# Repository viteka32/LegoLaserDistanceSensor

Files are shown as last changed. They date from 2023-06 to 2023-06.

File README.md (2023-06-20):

# LEGO® laser distance sensor
LEGO® laser distance sensor is open-source, which is used for robust distance measuring in educational robotic applications with LEGO® Mindstorms kits.
Advantages over the original LEGO® ultrasonic sensor:

 - Extended measurement range of up to 400 cm
 - Lower susceptibility to interference from other sensors
 - The refresh rate of up to 50 Hz
 - Based on [VL53L1x](https://www.st.com/en/imaging-and-photonics-solutions/vl53l1x.html) and [RP2040](https://www.raspberrypi.com/products/rp2040/)

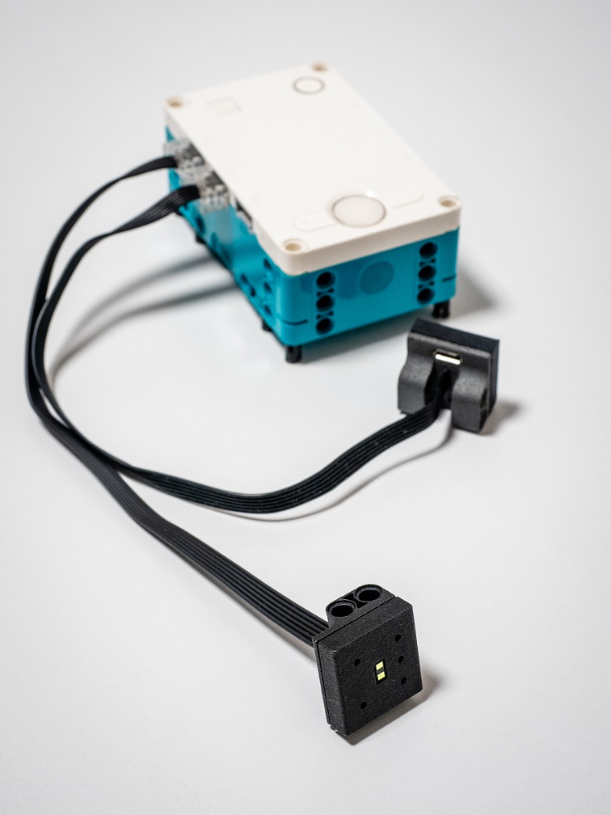
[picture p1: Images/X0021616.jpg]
Sensor


## LEGO® Mindstorms
The laser sensor is recognized in the LEGO® Mindstorms app as an original ultrasonic sensor. You can therefore use standard blocks for distance measurement.

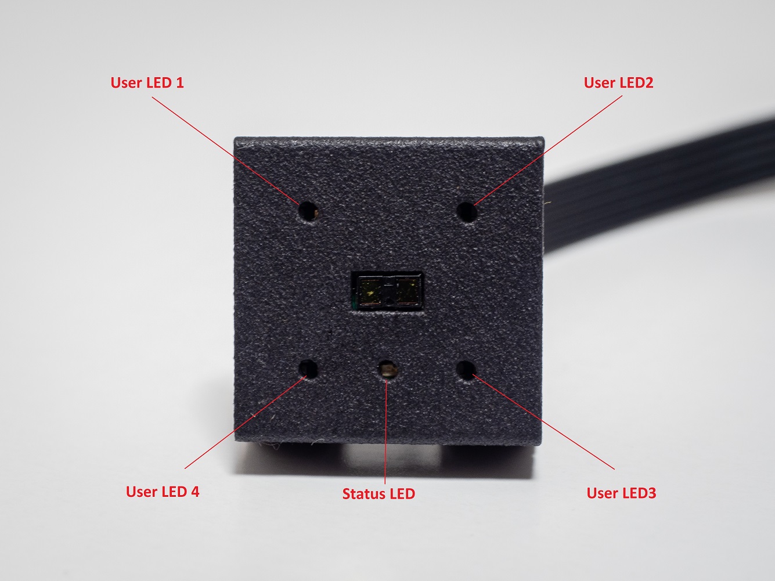
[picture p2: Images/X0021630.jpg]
LED description


#### Connection signalization
When connecting the laser sensor to LEGO® Spike/EV3, the status LED will flash. Once the laser sensor and LEGO® Spike/EV3 are correctly connected, the status LED will remain on.

#### Known issues
The laser sensor does not currently support additional LED illumination, making it incompatible with the ultrasonic sensor as a direct replacement.

## Hardware
The hardware is designed to operate with a power supply of either 3.3V or 5V, utilizing a low-drop LDO. The sensor can be used with LEGO® Spike (3.3V) or LEGO® EV3 (5V). For use with LEGO® EV3, an adapter is required to connect the sensor to the EV3 RJ12 connector. Alternatively, the laser distance sensor can be connected via a micro USB connector for programming custom applications in MicroPython or for use with a custom robotic application, such as Raspberry Pi.

### Issues - not tested
<span style="color:red">
The power supply control logic, which switches between the micro USB connector and the LEGO® Powered Up connector, has not been tested yet. We recommend unsoldering diode D6 and soldering resistor R15 (0R) to use the power supply solely from the LEGO® Powered Up connector.
</span>

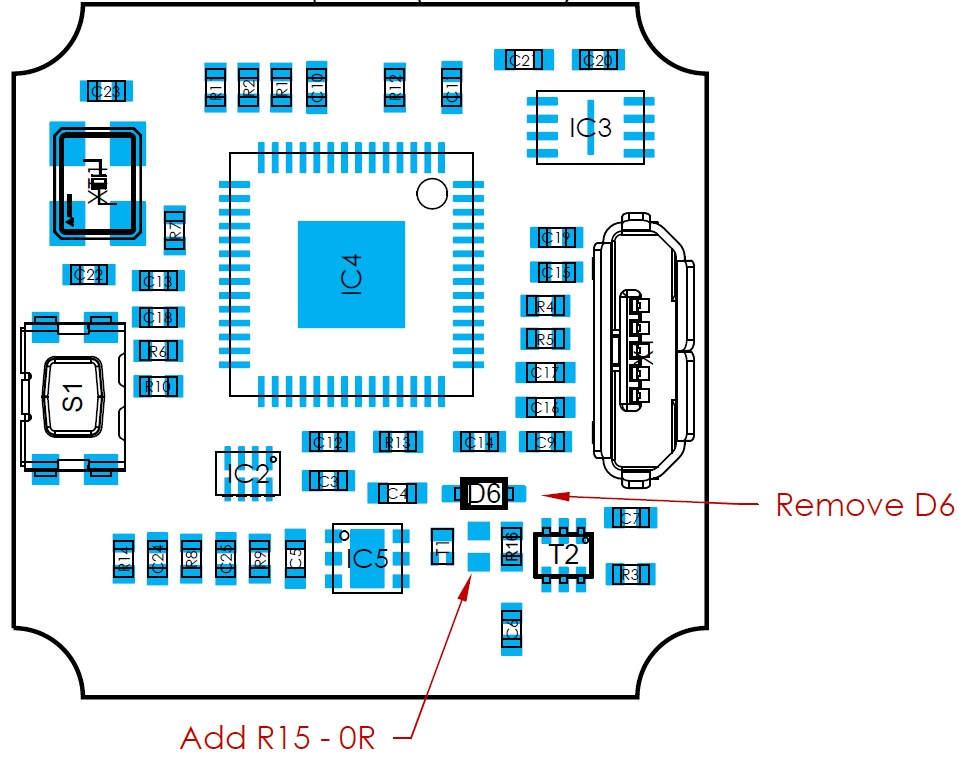
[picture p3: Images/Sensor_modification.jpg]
Sensor modification


### LEGO® Powered Up connector
https://www.aliexpress.com/item/1005004076370021.html?spm=a2g0o.order_list.order_list_main.98.2dce1802ppkqRz

## CAD models
The CAD folder contains files of the sensor case. It was designed for MJF 3D printer and it is recommended to use this type of printer.

## Software
### Requirements

- Python 3
- pip3
- rshell

#### Installing rshell
Linux:

```
pip3 install rshell
```

Windows:

```
python.exe -m pip install --upgrade pip
```

## How to bring the sensor up

### Flashing MicroPython Firmware
1. Press and hold the BOOTSEL button and plug your Lego Distance Sensor into the USB port of your computer. Release the BOOTSEL button after your Lego Distance Sensor is connected.
2. It will be detected as a Mass Storage Device called RPI-RP2.
3. Drag and drop the MicroPython UF2 file onto the RPI-RP2 storage.
4. Your Lego Distance Sensor will reboot and should be rediscovered by your system. If yes, you are now running MicroPython otherwise repeat step 1.
5. You can access micropython console using the REPL via USB Serial.

### Uploading Sensor Application Files
1. Connect to the Lego Distance Sensor's serial port from the command line.

   Linux:

   ```
   rshell -p /dev/ttyXXX --buffer-size 512
   ```

   Windows:

   ```
   rshell -p comXXX --buffer-size 512
   ```

2. Upload \*.py files

    ```
    cp main.py VL53L1X.py /pyboard
    ```

3. Verify that the \*.py files were successfully written.

    ```
    ls /pyboard
    ```

Alternatively, you can run a single command to perform these steps:

- Linux:

  ```
  rshell -p /dev/ttyXXX --buffer-size 512 cp main.py VL53L1X.py LPF2.py /pyboard
  ```

- Windows:

  ```
  rshell -p comXXX --buffer-size 512 cp main.py VL53L1X.py LPF2.py /pyboard
  ```

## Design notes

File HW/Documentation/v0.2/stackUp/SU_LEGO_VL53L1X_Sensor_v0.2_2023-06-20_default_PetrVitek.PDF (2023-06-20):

# Board Stack Report

Stack Up | Layer Stack
Layer | Board Layer Stack | Name | Material | Thickness | Constant

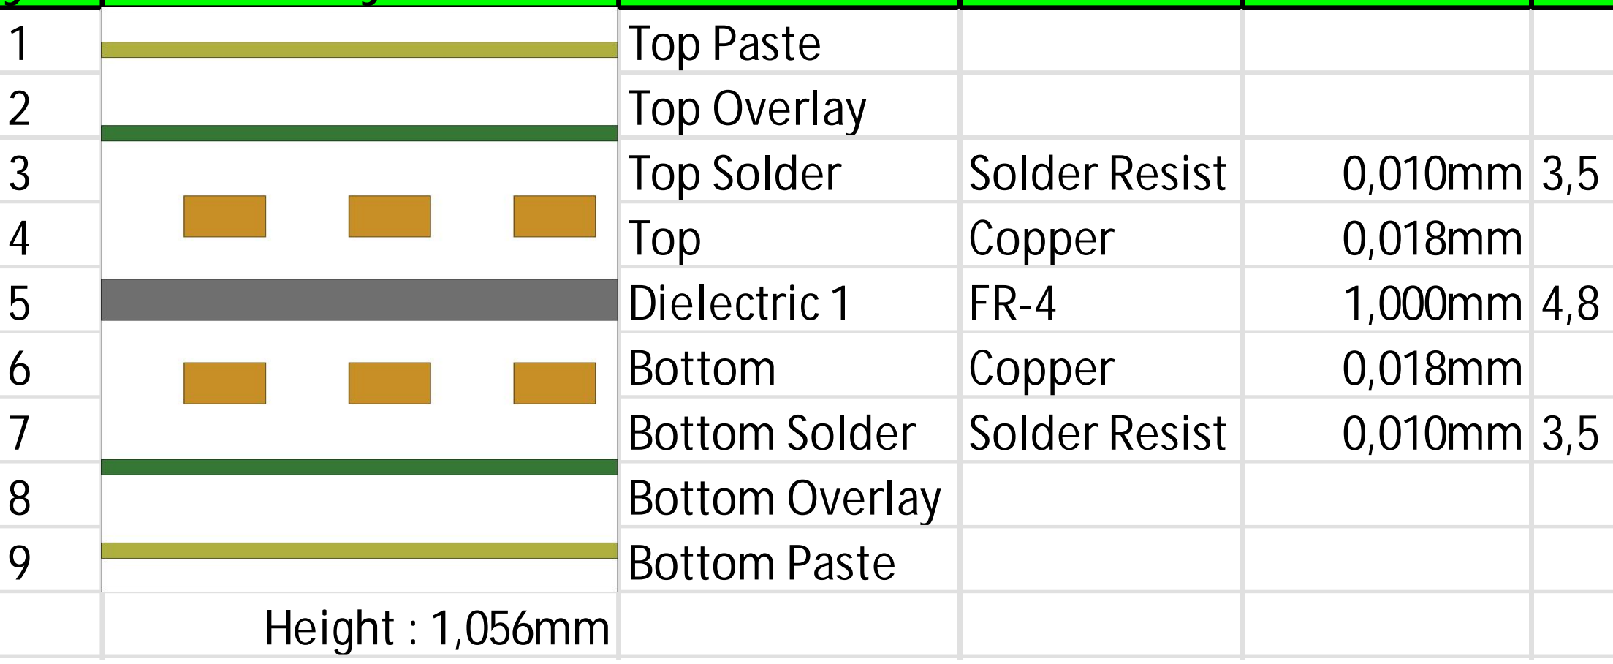
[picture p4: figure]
Top Paste; Top Overlay; Top Solder; Solder Resist; Top; Copper; Dielectric 1; Bottom; Bottom Solder; Bottom Overlay; Bottom Paste; Height : 1,056mm

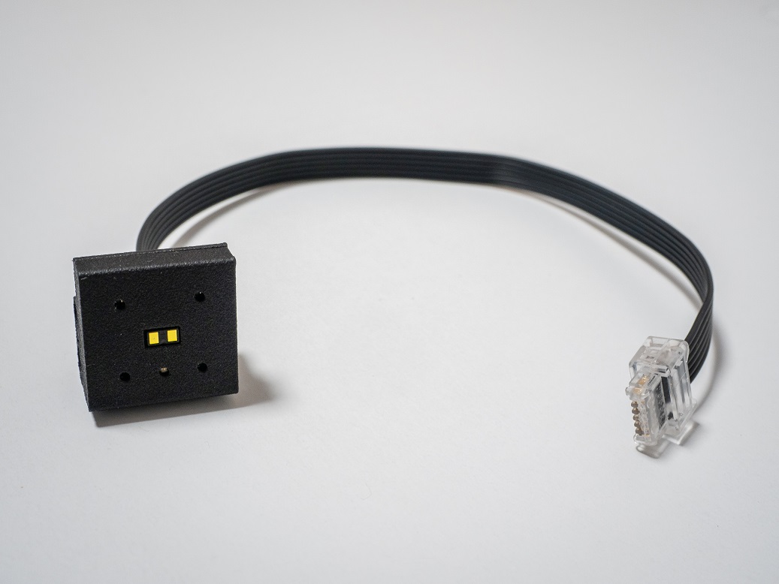
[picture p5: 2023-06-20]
Images/X0021620.jpg

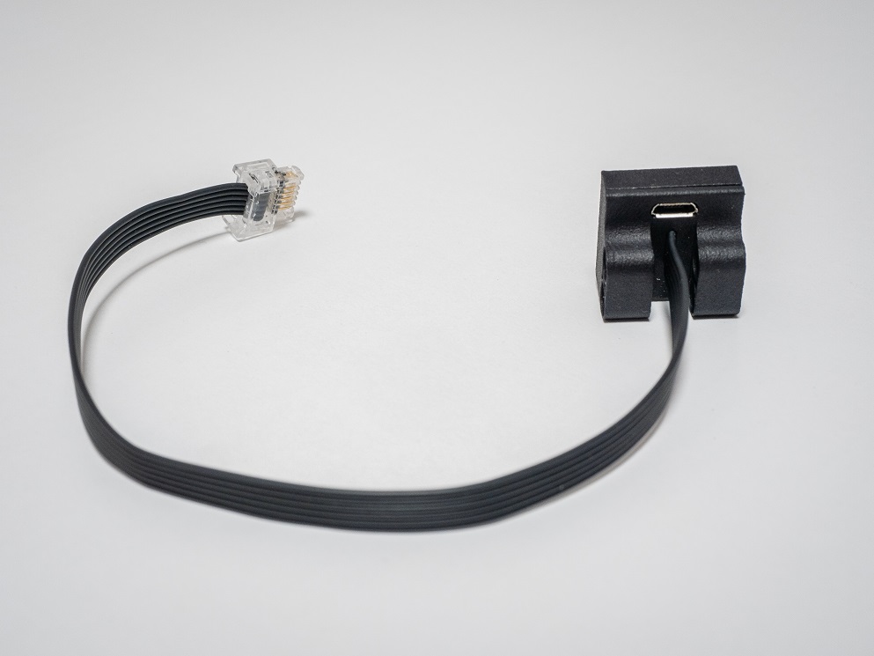
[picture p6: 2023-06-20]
Images/X0021623.jpg

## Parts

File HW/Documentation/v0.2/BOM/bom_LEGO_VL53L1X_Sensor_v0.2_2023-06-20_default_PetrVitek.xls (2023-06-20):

 |  |  |  |  |  |  |  |  |  |  | Release Date
 | Bill of Materials for | Lego Spike/EV3 Laser |  |  |  |  |  |  |  |  | 20.06.2023
 | Assembly Variant | default |  | Project Revision | v0.2
# | Reference | Value | Quantity | Package | Manufacturer | Part Number | Description | Supplier | Supplier Part Number | SZ | RČ
1 | C1, C3, C6, C7, C9, C10, C11, C12, C13, C14, C15, C18, C19, C20 | 100nF 25V | 14 | C0402 | Walsin Technologies | 0402B104K250CT | WALSIN - 0402B104K250CT - CAPACITOR, MLCC, X7R, 0.1UF, 25V, 0402 | Farnell | 2496772
2 | C2, C4, C5, C16, C17, C21 | 4.7uF/10V | 6 | C0402_big | Murata | GRM155R61A475MEAAD | MURATA - GRM155R61A475MEAAD - CAP, MLCC, X5R, 4.7UF, 10V, 0402 | Farnell | 2688503
3 | C22, C23 | 27pF 50V | 2 | C0402 | Walsin Technologies | 0402N270J500CT | WALSIN - 0402N270J500CT - CAPACITOR, MLCC, NP0, 27PF, 50V, 0402 | Farnell | 2496801
4 | C24, C25 | 10pF / 50V | 2 | C0402 | KEMET | C0402C100D5GAC | Kategorie produktu: Vícevrstvé keramické kondenzátory MLCC – pro povrchovou montáž SMD, SMT Výrobce: KEMET RoHS:: V souladu RoHS Údaje Série: C-C Kapacita: 10 pF Jmenovité napětí (DC) stejnosměrného proudu : 50 VDC Dielektrikum: C0G (NP0) Tolerance: 0.5 pF Kód pouzdra - palce: 0402 Kód pouzdra - mm: 1005 Výška: - Maximální provozní teplota: + 125 C Minimální provozní teplota: - 55 C Koncovka: - Výrobek: General Type MLCCs Obal: Cut Tape Obal: MouseReel Obal: Ree | Mouser | 80-C0402C100D5GAC
5 | D1, D2, D3, D4, D5 | KPH-1608SGC | 5 | LED0603 | Kingbright | KPH-1608SGC | KINGBRIGHT - KPH-1608SGC - LED, GREEN, 12MCD, 568NM, SMD LED 0603 zelená | Farnell | 2426215
6 | D6 | BAS716,115 | 1 | SOD523 | Nexperia | BAS716,115 | NEXPERIA - BAS716,115 - Small Signal Diode, Single, 85 V, 200 mA, 1.25 V, 3 µs, 4 A | Farnell | 8734500
7 | IC1 | VL53L1CXV0FY/1 | 1 | VL53L1X | STMicroelectronics | VL53L1CXV0FY/1 | STMICROELECTRONICS - VL53L1CXV0FY/1 - Proximity Sensor, I2C, 4000 mm, OLGA, 12 Pins, 2.6 V, 3.5 V | Farnell | 2851946
8 | IC2 | TXS0102DQMR | 1 | X2SON-8_1.8x1.2 | Texas Instruments | TXS0102DQMR | TEXAS INSTRUMENTS - TXS0102DQMR - Voltage Level Translator, 2 Inputs, 4.2ns, 1.65V to 5.5V, X2SON-8 | Farnell | 3050430
9 | IC3 | W25Q16JVUXIQ | 1 | USON-8_3x2 | Winbond | W25Q16JVUXIQ TR | Flash NOR spiFlash, 3V, 16M-bit, 4Kb Uniform Sector, DTR | Mouser | 454-W25Q16JVUXIQTR
10 | IC4 | RP2040CT | 1 | QFN56 | Raspberry Pi | RP2040CT | RASPBERRY-PI - RP2040CT - ARM MCU, RP2040 Series Microcontrollers, ARM Cortex-M0+, 32bit, 133 MHz, 16 MB, 264 KB | Farnell | 3766082
11 | IC5 | NCP705MT33TCG | 1 | WDFN6 | ON Semiconductor | NCP705MT33TCG | Regulátory napětí s nízkým úbytkem (LDO) 500 MA LDO ULTRA-LOW IQ | Mouser | 863-NCP705MT33TCG
12 | R1, R2, R3, R10, R11, R12, R13, R14 | 2k2 | 8 | R0402 | Vishay | CRCW04022K20FKED | VISHAY - CRCW04022K20FKED. - RES, THICK FILM, 2K2, 1%, 0.063W, 0402 | Farnell | 2140802
13 | R4, R5, R8, R9 | 27R | 4 | R0402 | Vishay | CRCW040227R0FKED | VISHAY - CRCW040227R0FKED. - SMD Chip Resistor, 27 ohm, ± 1%, 62.5 mW, 0402 [1005 Metric], Thick Film, General Purpose | Farnell | 2140614
14 | R6, R7, R16 | 1k 1% | 3 | R0402 | Vishay Dale | CRCW04021K00FKED | VISHAY - CRCW04021K00FKED - RES, THICK FILM, 1K, 1%, 0.063W, 0402 | Farnell | 1469662
15 | S1 | KMR211G LFS | 1 | ButtonKMR2 | ITT C&K | KMR211GLFS | C & K COMPONENTS - KMR211G LFS - SWITCH, SPST, 0.05A, 32VDC, SMD | Farnell | 1437635
16 | T1 | PBSS2515M | 1 | DFN1006-3 | NXP Semiconductors | PBSS2515M,315 | NEXPERIA - PBSS2515M,315 - TRANSISTOR, BIPOLAR | Mouser | 771-PBSS2515M315
17 | T2 | EMH53T2R | 1 | SOT-563-6 | Rohm | EMH53T2R | ROHM - EMH53T2R - Bipolar Pre-Biased / Digital Transistor, Dual NPN, 50 V, 100 mA, 4.7 kohm | Farnell | 3757495
18 | X1 | USB3131-30-0230-A | 1 | USB3131-XX-0230-X | Global Connector Technology | USB3131-30-0230-A | GCT (GLOBAL CONNECTOR TECHNOLOGY) - USB3131-30-0230-A - USB Connector, Micro USB Type B, USB 2.0, Receptacle, 5 Ways, Through Hole Mount, Vertical | Farnell | 2537022
19 | XT1 | 12 MHz | 1 | ABM8 | Abracon | ABM8-12.000MHZ-B2-T | Krystaly 12.0 MHZ 18PF 20PPM 120OHM | Mouser | 815-ABM8-12-B2-T
 |  | Total Quantity | 55

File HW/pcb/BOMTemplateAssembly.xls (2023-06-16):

 |  |  |  |  |  |  |  |  |  |  | Release Date
 | Bill of Materials for | Field=projectTitle |  |  |  |  |  |  |  |  | Field=ReportDate
 | Assembly Variant | Field=VariantName |  | Project Revision | Field=projectRevision
# | Reference | Value | Quantity | Package | Manufacturer | Part Number | Description | Supplier | Supplier Part Number | SZ | RČ
1
2
3
 |  | Total Quantity | 0

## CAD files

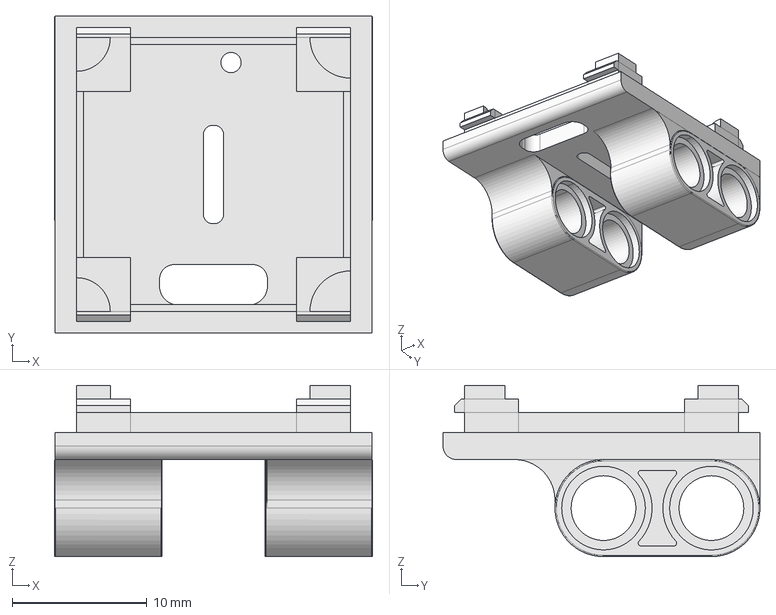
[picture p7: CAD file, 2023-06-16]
CAD/CaseBottom.step
23.6 x 23.5 x 12.7 mm

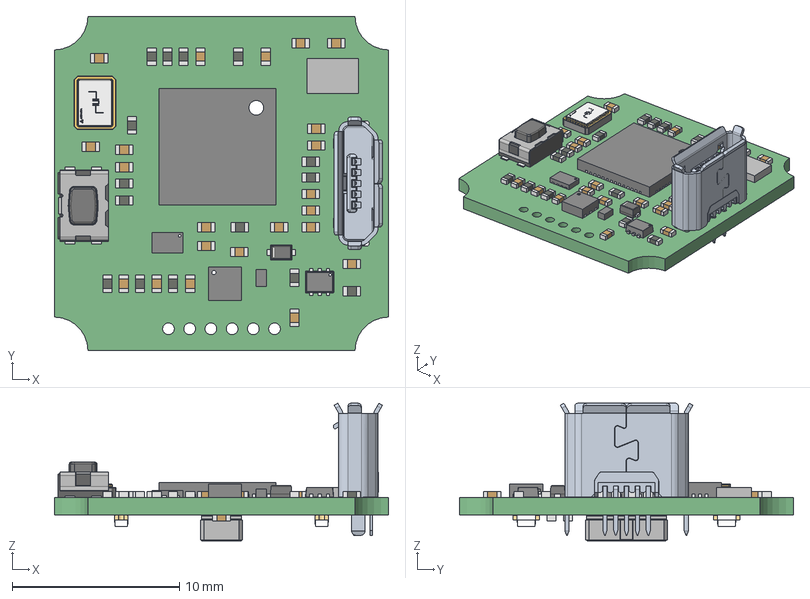
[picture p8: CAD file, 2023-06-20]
HW/Documentation/v0.2/Step/STEP_LEGO_VL53L1X_Sensor_v0.2_2023-06-20_default_PetrVitek.step
20.0 x 20.0 x 8.24 mm
Extruded x 118
bigPin
smallPine x 2
lead x 6
SOD-523F
User Library-Switch-CK-KMR2_Button
User Library-Switch-CK-KMR2_Boitier
User Library-Switch-CK-KMR2_Tole
User Library-Switch-CK-KMR2_Pads
Thermal_Shape x 2
housing x 5
cover x 5
base x 10
Polarity Mark x 5
MSBR-3
MSBR-4
MSBR-6
MSBR-5
MSBR-7
MSBR-1
MSBR-2
bracon Logo yure
pcb
kork
pads
blend
lens
main
blocker

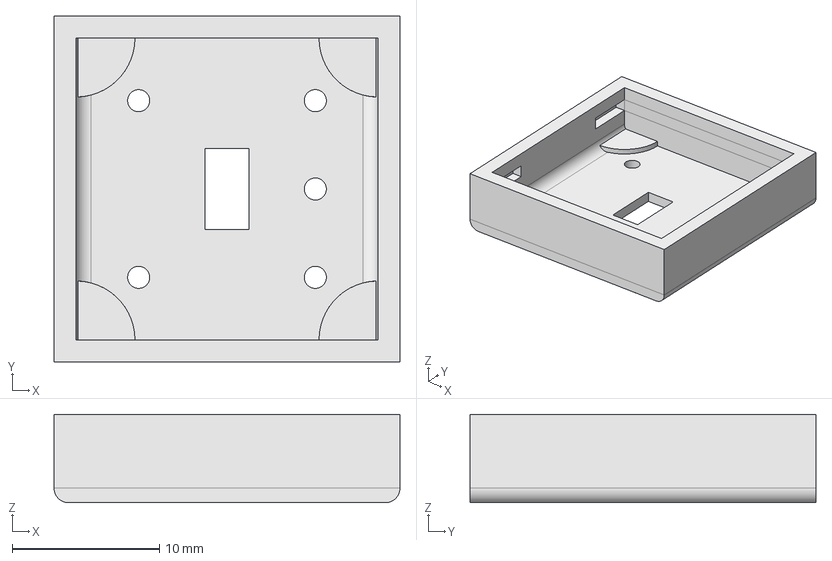
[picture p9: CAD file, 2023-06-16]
CAD/CaseTop.step
23.5 x 23.5 x 6.00 mm

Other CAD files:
HW/Documentation/v0.2/Step/STEP_LEGO_VL53L1X_Sensor_v0.2_2023-02-10_default_PetrVitek.step
CAD/CaseBottom.FCStd
CAD/CaseBottom.stl
CAD/CaseTop.FCStd
CAD/CaseTop.stl

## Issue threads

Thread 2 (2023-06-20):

Test and rework power supply control logic

viteka32, 2023-06-20:

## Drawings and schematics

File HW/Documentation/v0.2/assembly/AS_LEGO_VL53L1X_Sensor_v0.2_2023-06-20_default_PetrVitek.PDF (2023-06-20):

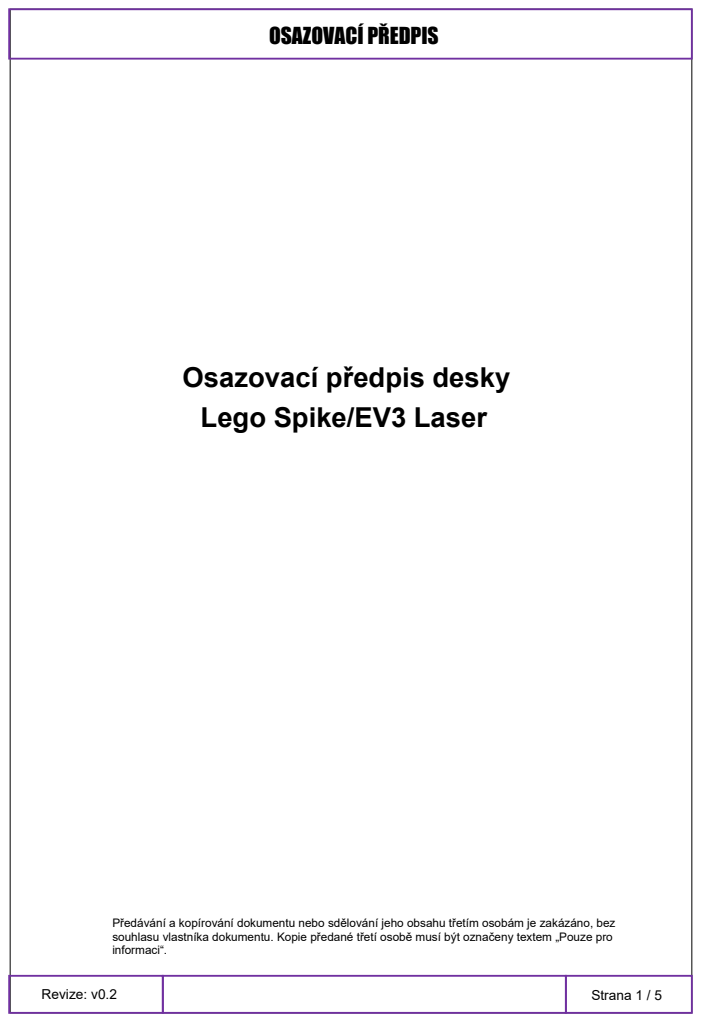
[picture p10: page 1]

Předávání a kopírování dokumentu nebo sdělování jeho obsahu třetím osobám je zakázáno, bez
souhlasu vlastníka dokumentu. Kopie předané třetí osobě musí být označeny textem „Pouze pro
informaci“.

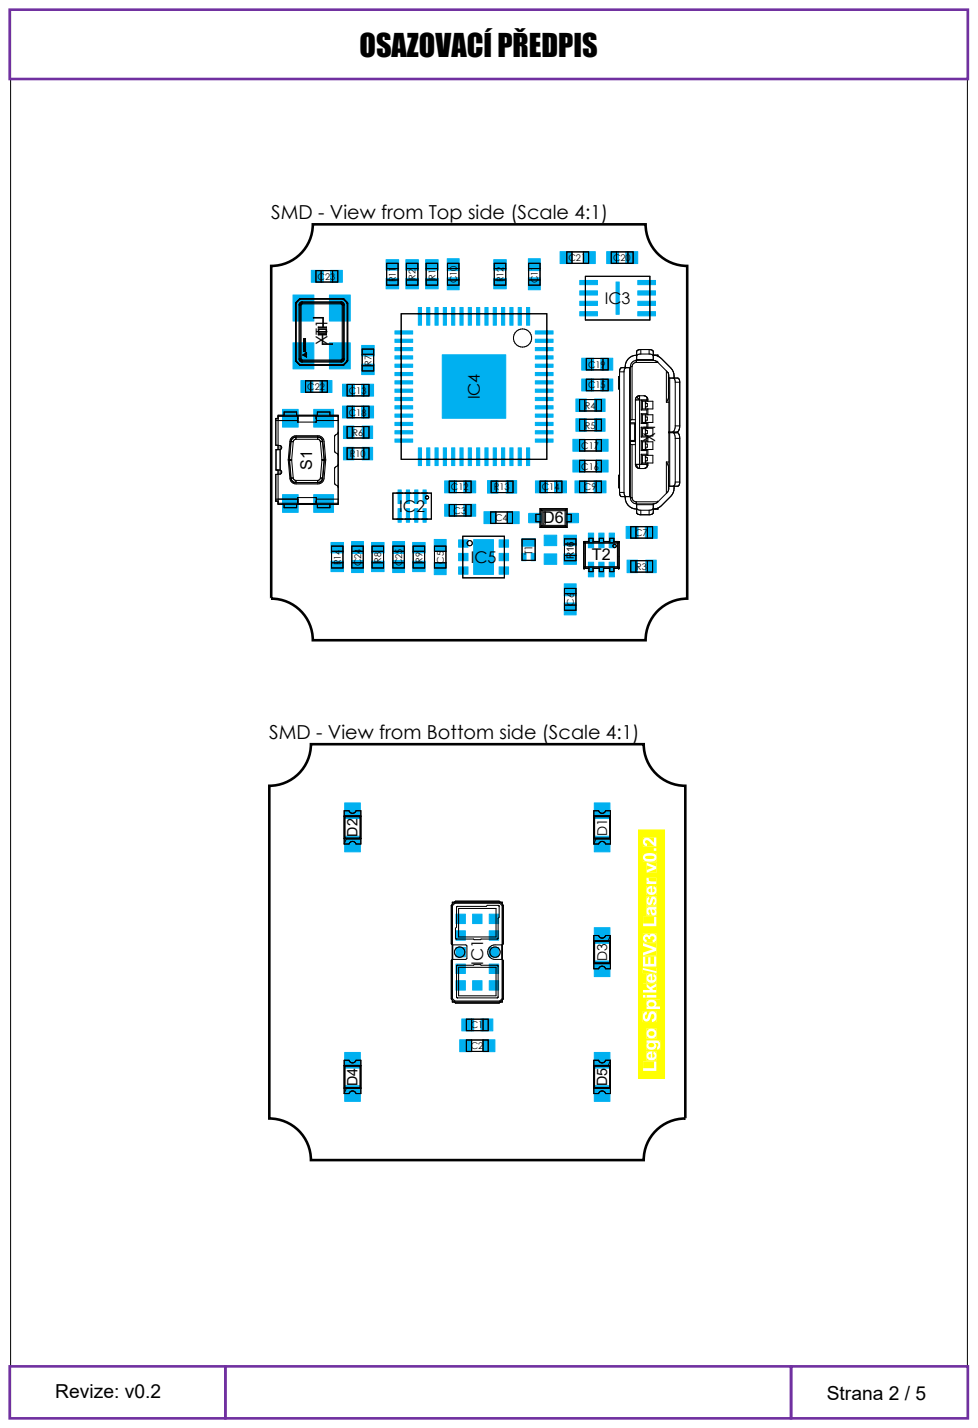
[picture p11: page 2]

SMD - View from Top side (Scale 4:1)

SMD - View from Bottom side (Scale 4:1) R16 R7

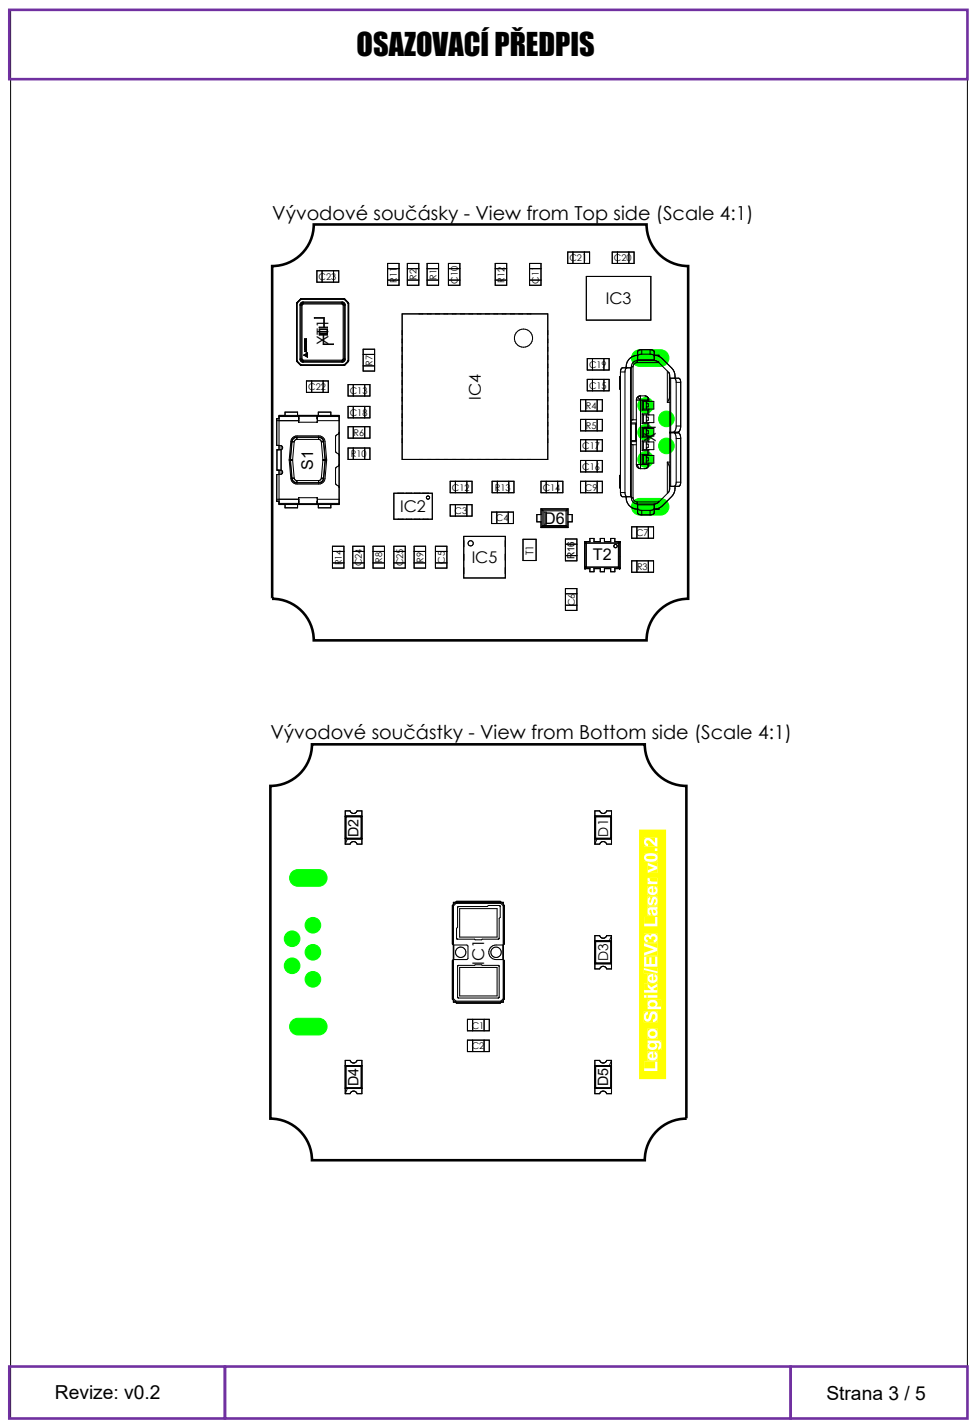
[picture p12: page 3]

Vývodové součásky - View from Top side (Scale 4:1)

Vývodové součástky - View from Bottom side (Scale 4:1)

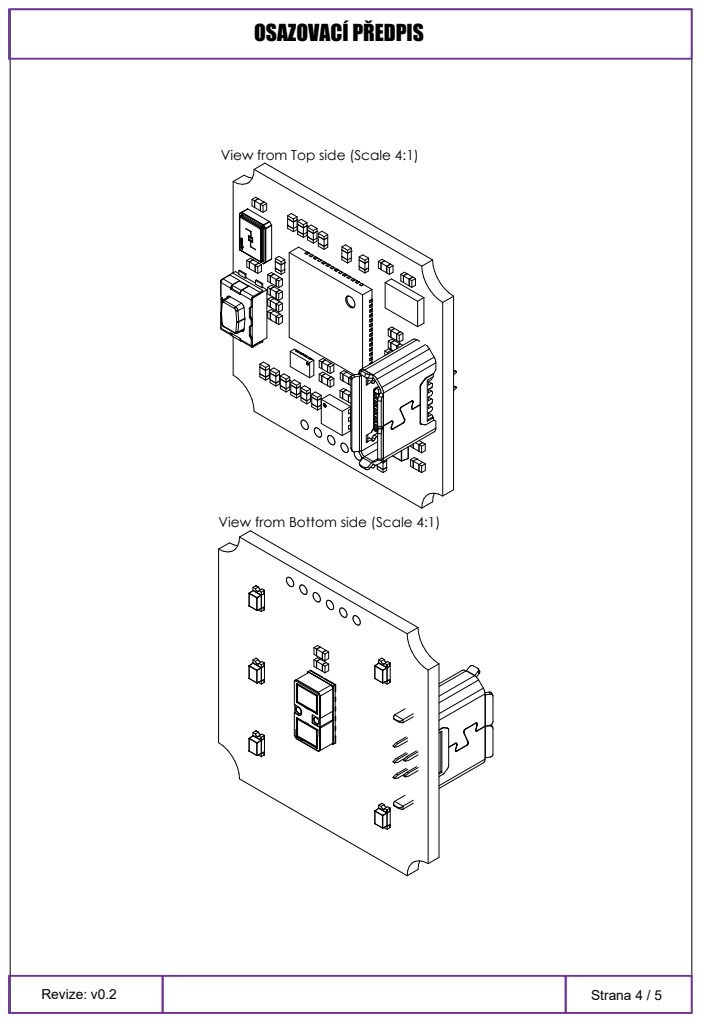
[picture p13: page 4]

View from Top side (Scale 4:1)

View from Bottom side (Scale 4:1)

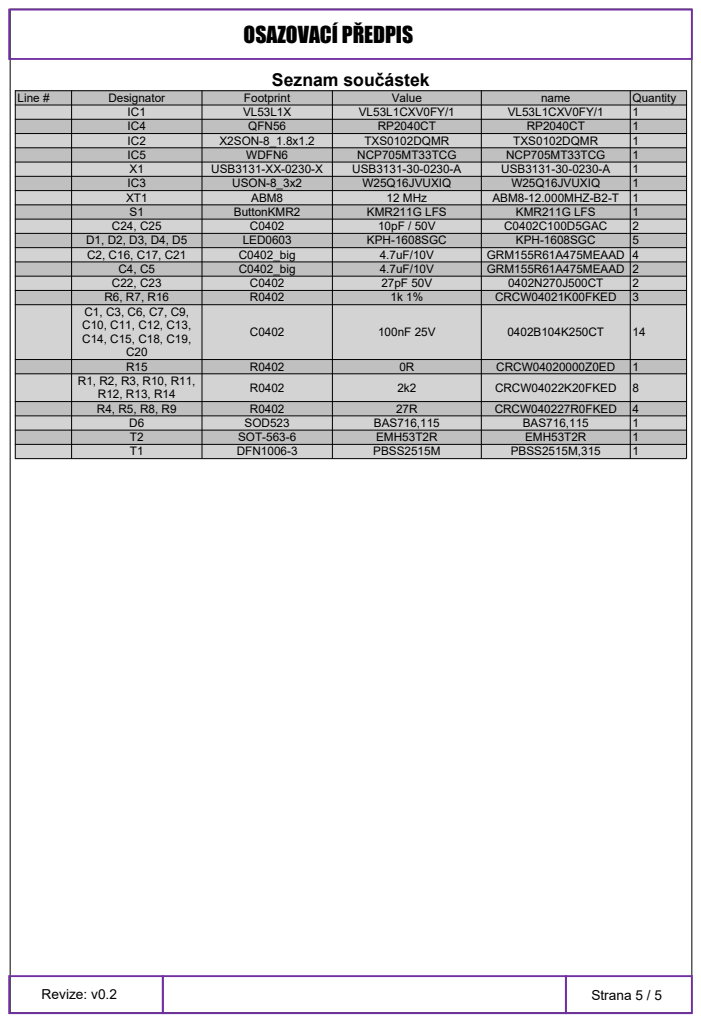
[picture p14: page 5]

Line # | Designator | Footprint | Value | name | Quantity

IC1 | VL53L1X | VL53L1CXV0FY/1 | VL53L1CXV0FY/1 | 1
IC4 | QFN56 | RP2040CT | RP2040CT | 1
IC2 | X2SON-8_1.8x1.2 | TXS0102DQMR | TXS0102DQMR | 1
IC5 | WDFN6 | NCP705MT33TCG | NCP705MT33TCG | 1
X1 | USB3131-XX-0230-X | USB3131-30-0230-A | USB3131-30-0230-A | 1
IC3 | USON-8_3x2 | W25Q16JVUXIQ | W25Q16JVUXIQ | 1
XT1 | ABM8 | 12 MHz | ABM8-12.000MHZ-B2-T | 1
S1 | ButtonKMR2 | KMR211G LFS | KMR211G LFS | 1
C24, C25 | C0402 | 10pF / 50V | C0402C100D5GAC | 2
D1, D2, D3, D4, D5 | LED0603 | KPH-1608SGC | KPH-1608SGC | 5
C2, C16, C17, C21 | C0402_big | 4.7uF/10V | GRM155R61A475MEAAD | 4
C4, C5 | C0402_big | 4.7uF/10V | GRM155R61A475MEAAD | 2
C22, C23 | C0402 | 27pF 50V | 0402N270J500CT | 2
R6, R7, R16 | R0402 | 1k 1% | CRCW04021K00FKED | 3
C1, C3, C6, C7, C9, C10, C11, C12, C13, C14, C15, C18, C19, C20 | C0402 | 100nF 25V | 0402B104K250CT | 14

R15 | R0402 | 0R | CRCW04020000Z0ED | 1

R1, R2, R3, R10, R11, R12, R13, R14 | R0402 | 2k2 | CRCW04022K20FKED | 8

R4, R5, R8, R9 | R0402 | 27R | CRCW040227R0FKED | 4
D6 | SOD523 | BAS716,115 | BAS716,115 | 1
T2 | SOT-563-6 | EMH53T2R | EMH53T2R | 1
T1 | DFN1006-3 | PBSS2515M | PBSS2515M,315 | 1

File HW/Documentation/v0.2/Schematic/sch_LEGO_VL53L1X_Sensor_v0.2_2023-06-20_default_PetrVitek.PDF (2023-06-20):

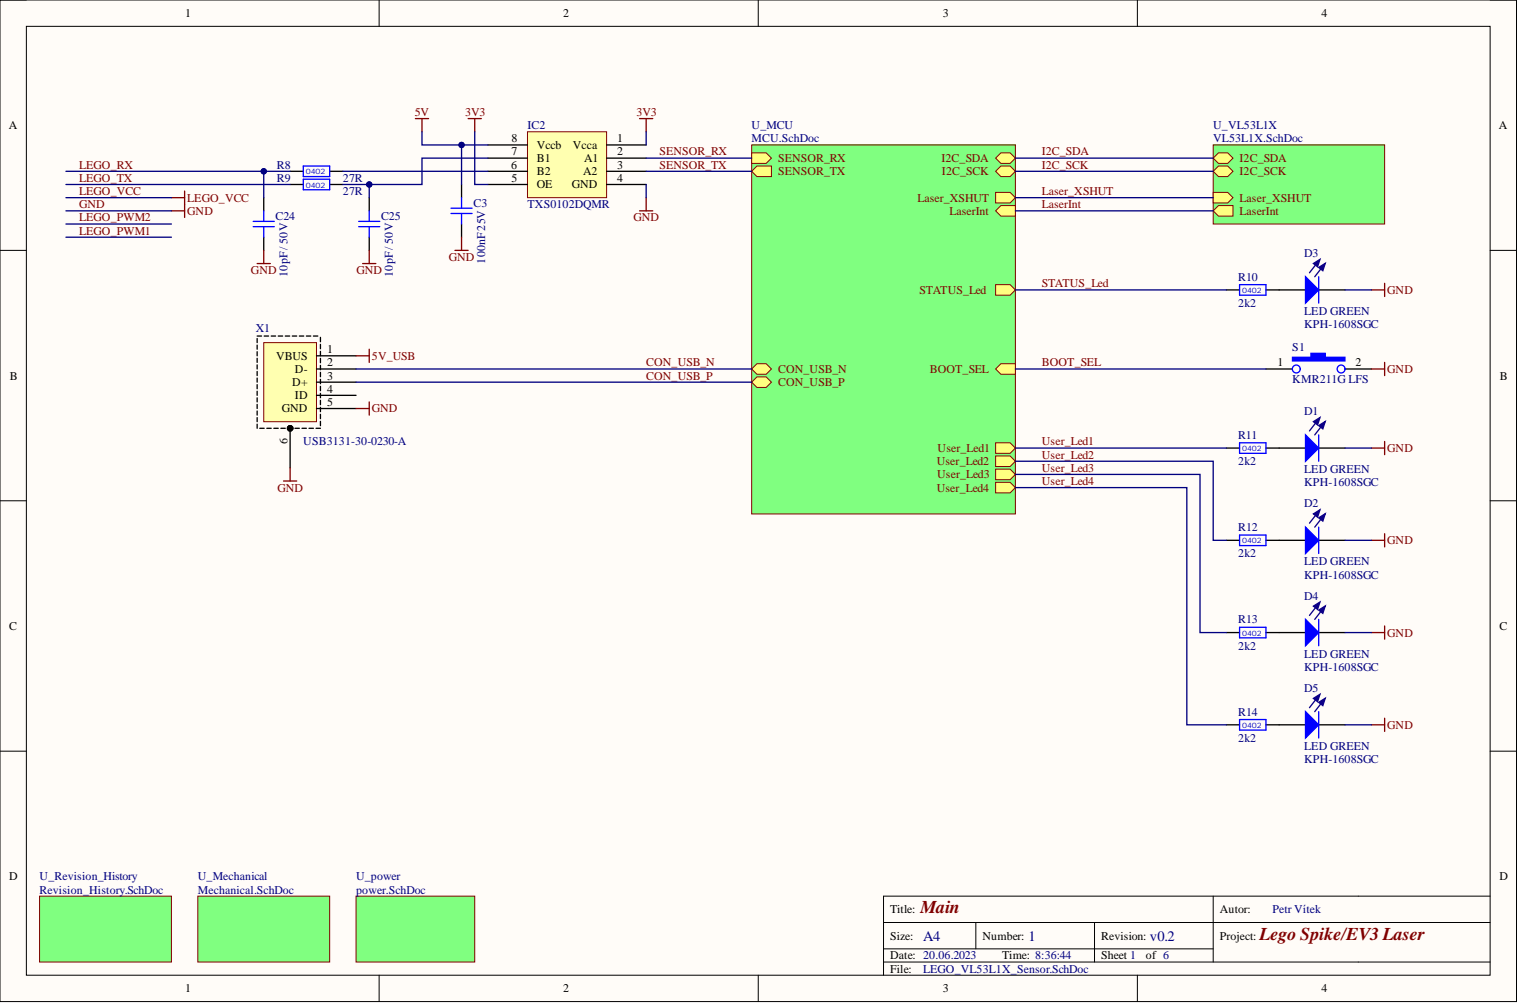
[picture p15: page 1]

6 | 3 SE NSOR_ T X | I2C_SC K

0 4 0 2 | 2 7 R | | 5 | 4 | Laser_ XSH U T

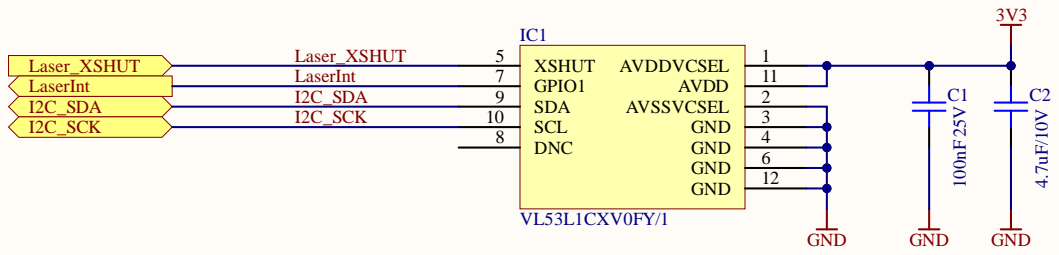
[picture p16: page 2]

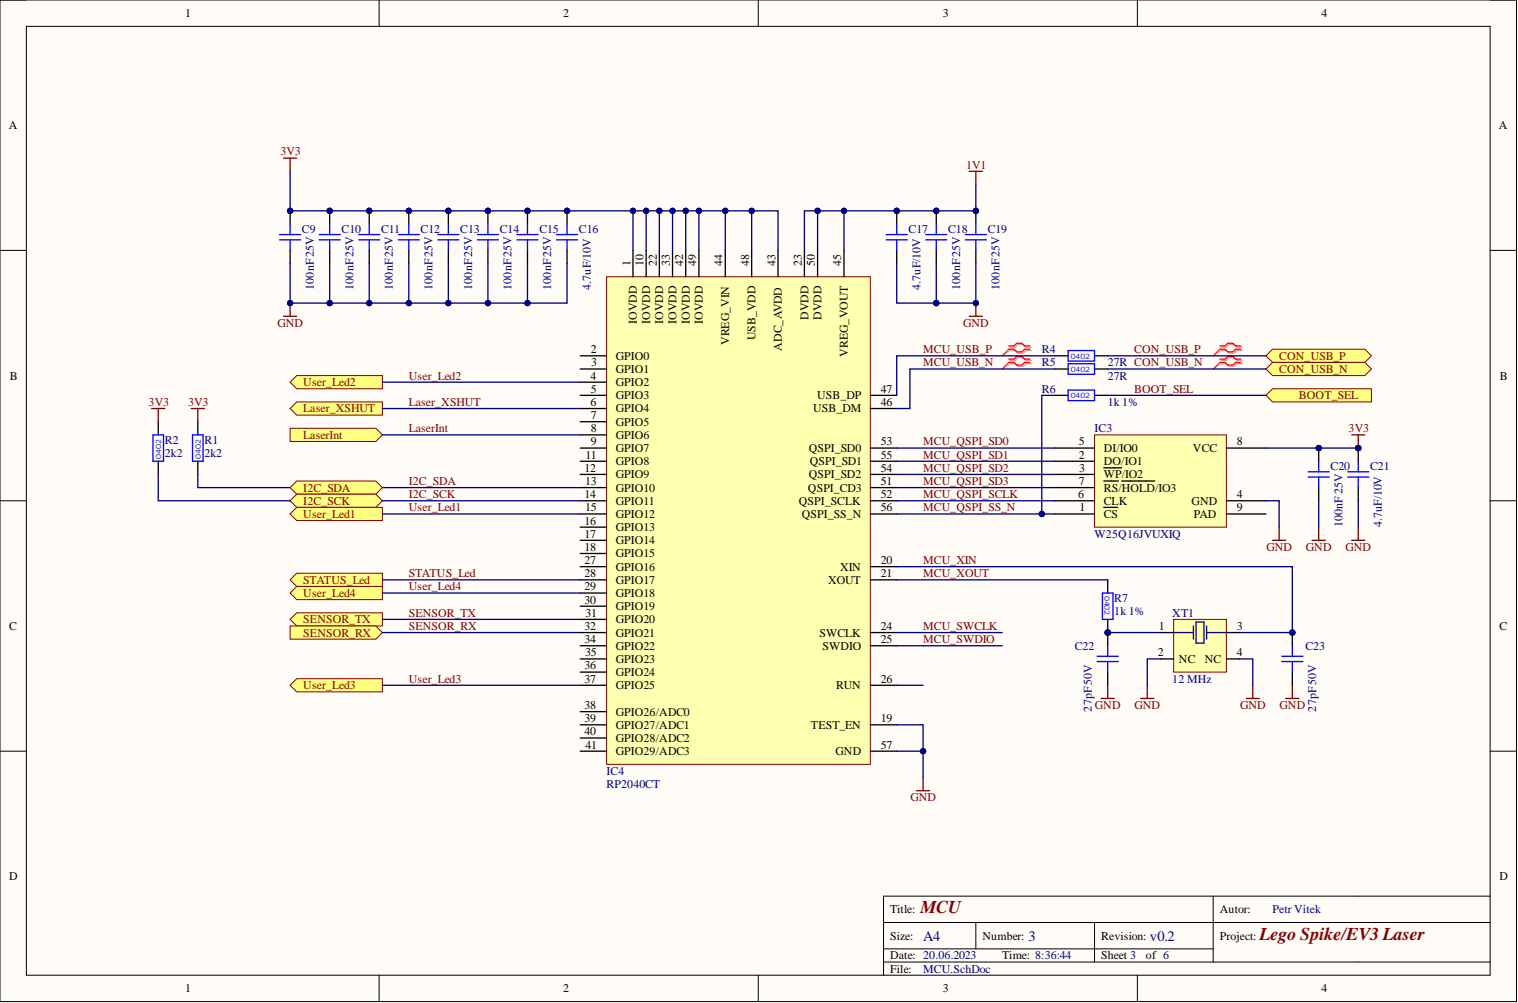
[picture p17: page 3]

MCU_QSPI_SD1 | DO/IO1 2
MCU_QSPI_SD2 | WP/IO2 3
MCU_QSPI_SD3 | RS/HOLD/IO3 7

Project: Lego Spike/EV3 Laser

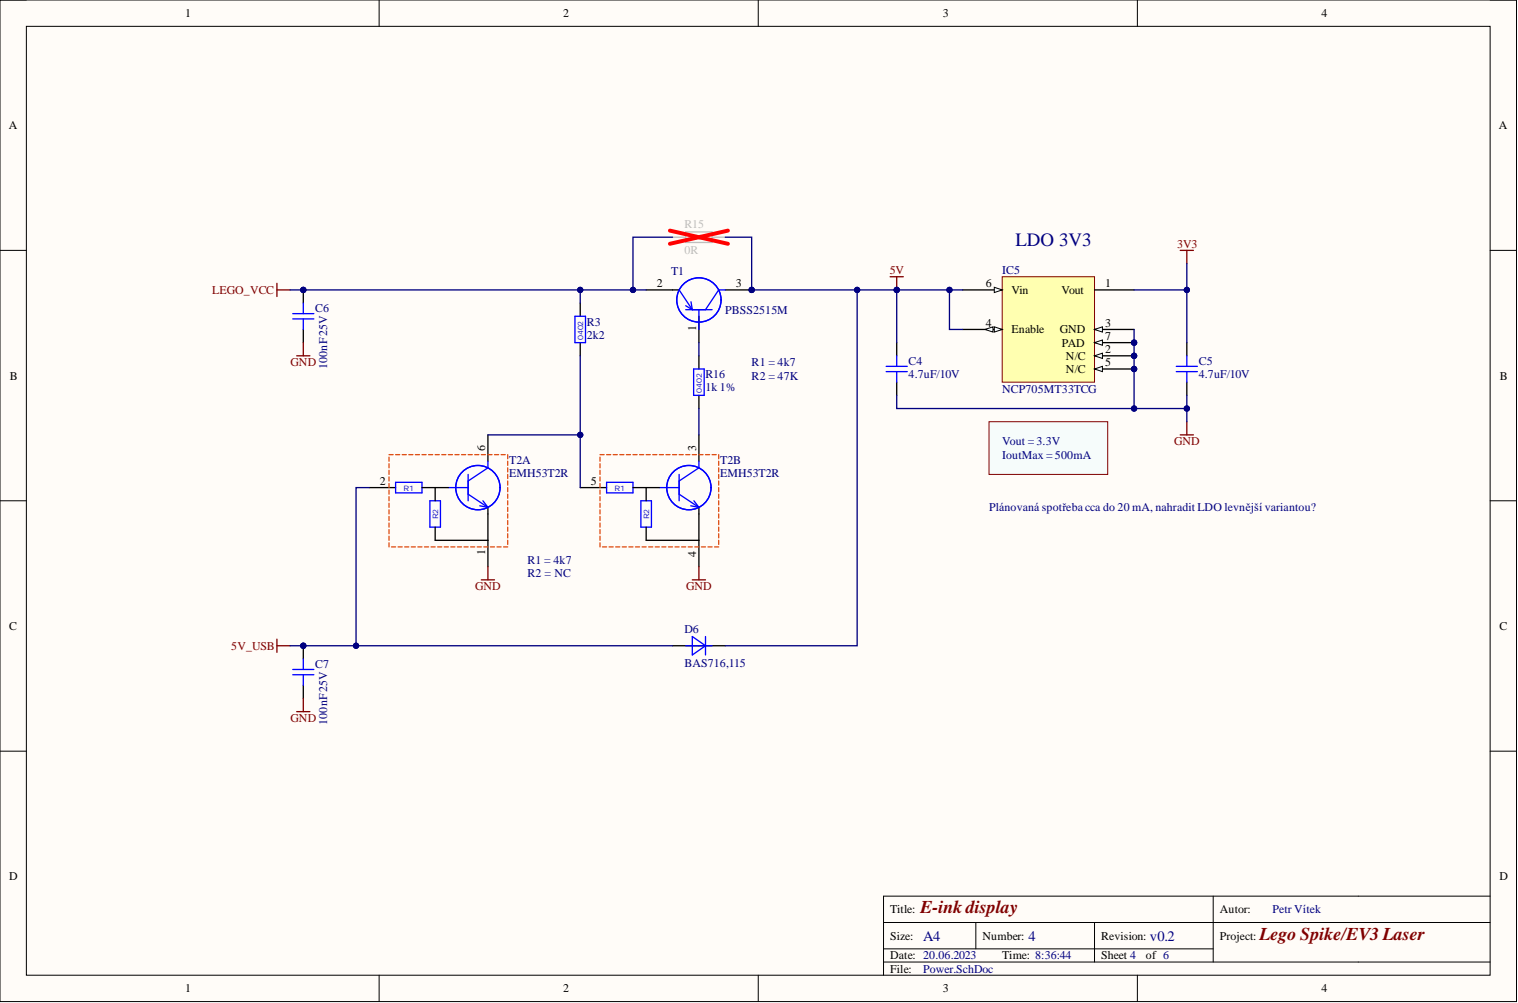
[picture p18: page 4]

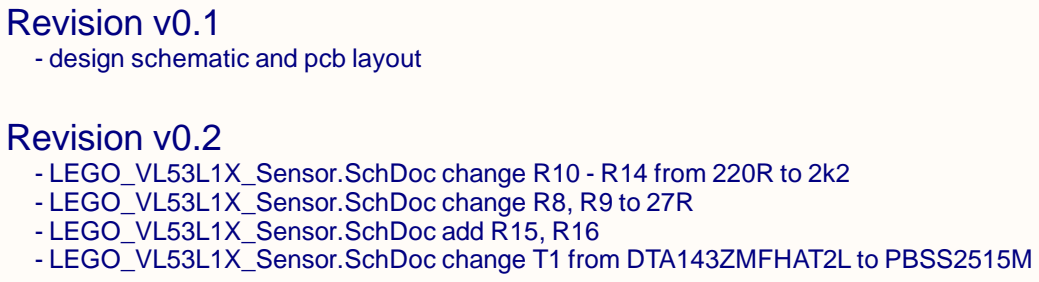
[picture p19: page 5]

Revision v0.1 - design schematic and pcb layout

Revision v0.2 - LEGO_VL53L1X_Sensor.SchDoc change R10 - R14 from 220R to 2k2

- LEGO_VL53L1X_Sensor.SchDoc change R8, R9 to 27R
- LEGO_VL53L1X_Sensor.SchDoc add R15, R16
- LEGO_VL53L1X_Sensor.SchDoc change T1 from DTA143ZMFHAT2L to PBSS2515M

Project: Lego Spike/EV3 Laser

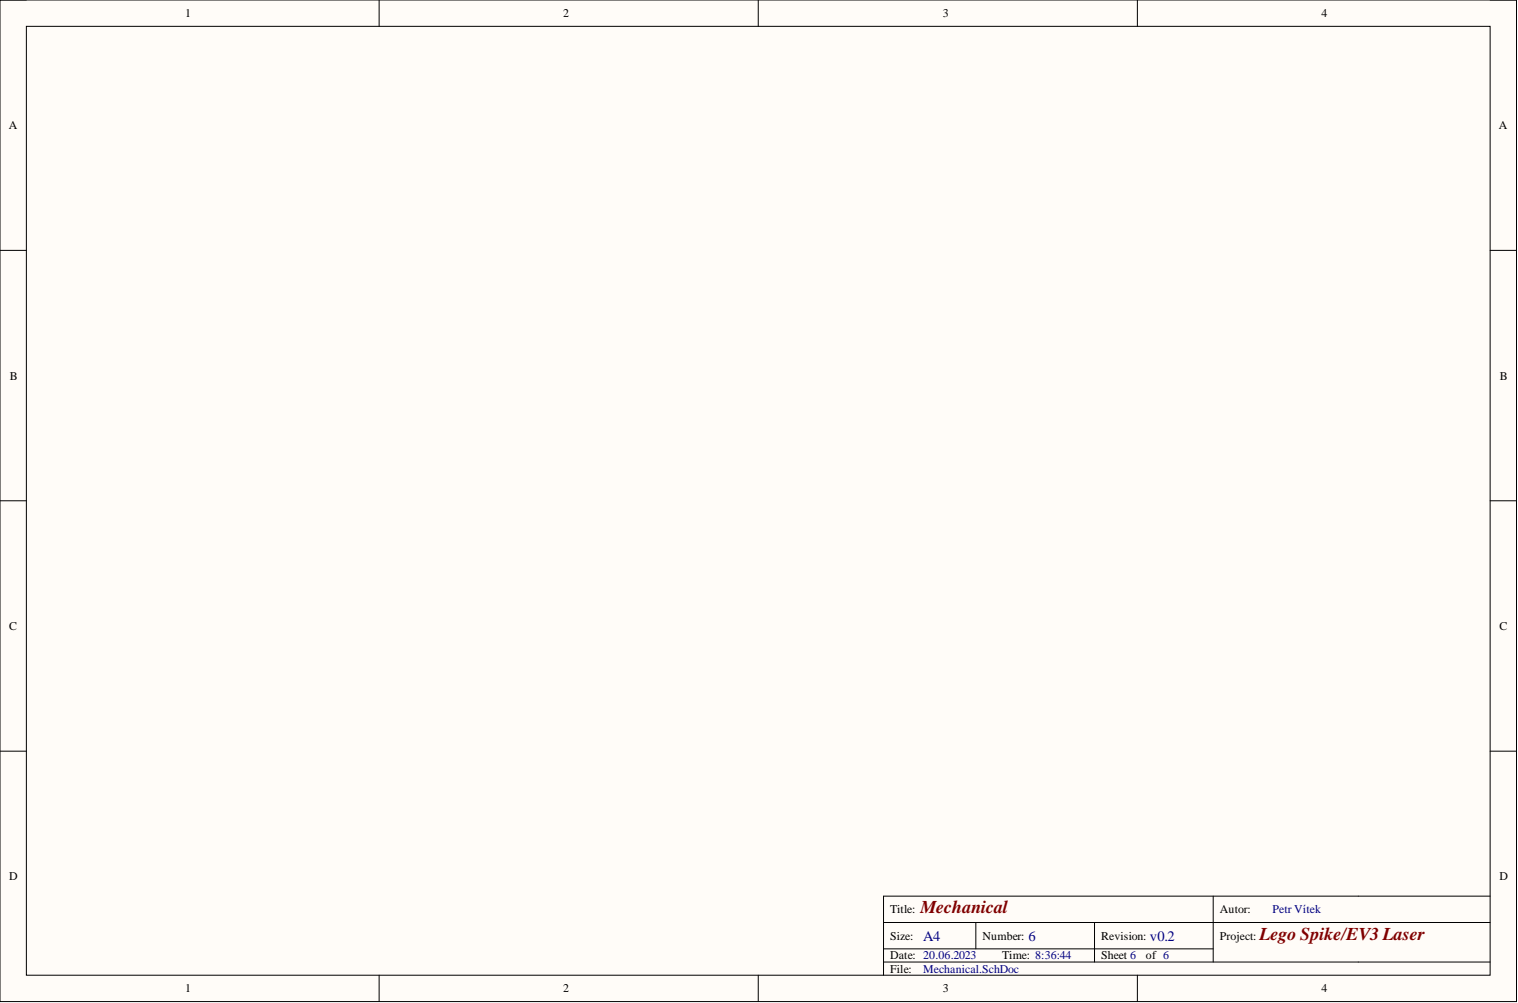
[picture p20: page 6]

Project: Lego Spike/EV3 Laser

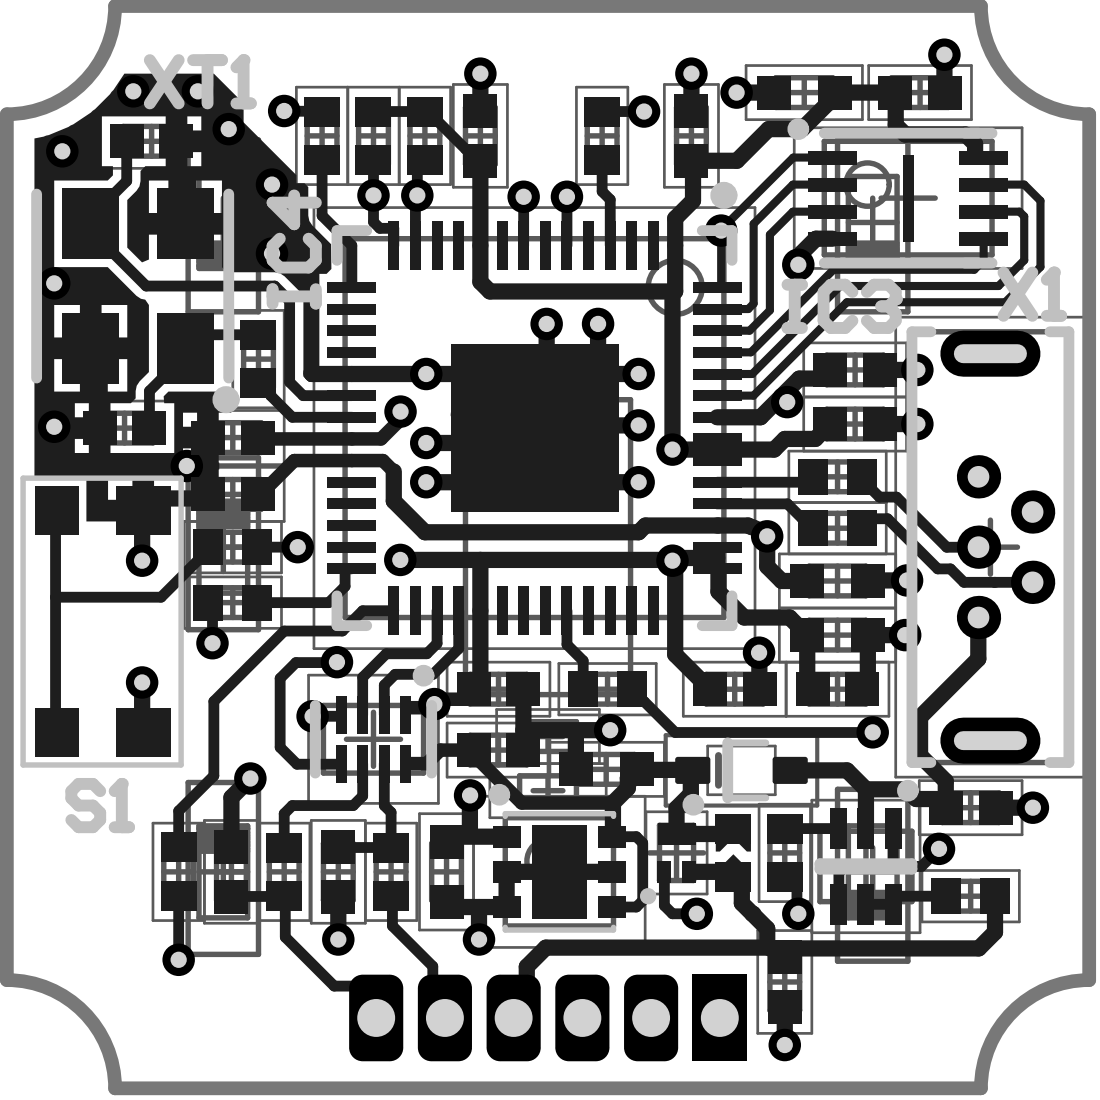
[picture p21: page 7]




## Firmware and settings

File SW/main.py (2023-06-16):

from utime import sleep_ms
import LPF2
from machine import I2C,Pin
import machine
from VL53L1X import VL53L1X

def ledCallback(timerInfo):
      if not lpf2.connected:
           led.toggle()
      print(value)
      
value = 0
 
led = Pin(17, mode=Pin.OUT)
led.on()
ledTimer = machine.Timer(-1, period=500, callback=ledCallback)

# Name, Format [# datasets, type, figures, decimals], 
# raw [min,max], Percent [min,max], SI [min,max], Symbol, functionMap [type, ?], view

# SPIKE
mode0 = ['DISTANCE',[1,LPF2.DATA16,3,0],[0,900],[0,100],[0,900],'RAW',[LPF2.ABSOLUTE,0],True]
# EV3
#mode0 = ['DISTANCE',[1,LPF2.DATAF,3,0],[0,900],[0,100],[0,900],'RAW',[LPF2.ABSOLUTE,0],True]

modes = [mode0]

txpin=20
rxpin=21   

pin1 = Pin(rxpin, mode=Pin.OUT)
pin1.on()
pin0 = Pin(txpin, mode=Pin.OUT)
pin0.off()

# SPIKE
lpf2 = LPF2.LPF2(1, txpin,rxpin, modes, LPF2.SPIKE_Ultrasonic, timer = -1, freq = 50)  
# EV3  
#lpf2 = LPF2.LPF2(1, txpin,rxpin, modes, LPF2.Ev3_Utrasonic, timer = -1, freq = 50)    

lpf2.initialize()

# set laser xshut to value 1
pin_xShut = Pin(4, mode=Pin.OUT)
pin_xShut.on()
# set laser int to input
pin_int = Pin(6, mode=Pin.IN)
i2c = I2C(1, scl=Pin(11), sda=Pin(10), freq=100000)
print("Laser address:")
print(i2c.scan())
distanceSensor = VL53L1X(i2c)

# Loop
while True:
     try:
          if not lpf2.connected:
               lpf2.sendTimer.deinit()
               sleep_ms(200)
               lpf2.initialize()
               value = 0
          else:
               led.on()
               value = int(distanceSensor.read() / 10);
               lpf2.load_payload('Int16',[value])
               sleep_ms(20)
     except:
          lpf2.close() # clean up
          raise

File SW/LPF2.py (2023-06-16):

'''
LEGO SPIKE Prime Backpacks
LPF2 class allows communication between LEGO SPIKE Prime and LEGO Backpacks
Version Date: 01/06/2020
Tufts Center for Engineering Education and Outreach
Tufts University
Updated on: 01/06/2020
'''
import machine, utime, gc
import math, struct

BYTE_NACK = 0x02
BYTE_ACK = 0x04
CMD_Type = 0x40   # set sensor type command
CMD_Select = 0x43   #sets modes on the fly
CMD_Mode = 0x49   # set mode type command
CMD_Baud = 0x52   # set the transmission baud rate
CMD_Vers = 0x5F   # set the version number
CMD_ModeInfo = 0x80  # name command
CMD_Data  = 0xC0  # data command

CMD_LLL_SHIFT = 3

NAME,RAW,Pct,SI,SYM,FCT, FMT = 0x0,0x1,0x2,0x3,0x4,0x5, 0x80
DATA8,DATA16,DATA32,DATAF = 0,1,2,3  # Data type codes
ABSOLUTE,RELATIVE,DISCRETE = 16,8,4
WeDo_Ultrasonic, SPIKE_Color, SPIKE_Ultrasonic = 35, 61, 62
Ev3_Utrasonic = 30  

length = {'Int8' : 1, 'uInt8' : 1, 'Int16' : 2, 'uInt16' : 2, 'Int32' : 4, 'uInt32' : 4, 'float' : 4}
format = {'Int8' : '<b', 'uInt8' : '<B', 'Int16' : '<h', 'uInt16' : '<H', 
     'Int32' : '<l', 'uInt32' : '<L', 'float' : '<f'}

# Name, Format [# datasets, type, figures, decimals], 
# raw [min,max], Percent [min,max], SI [min,max], Symbol, functionMap [type, ?], view
mode0 = ['LPF2-DETECT',[1,DATA8,3,0],[0,10],[0,100],[0,10],'',[ABSOLUTE,0],True]
mode1 = ['LPF2-COUNT',[1,DATA32,4,0],[0,100],[0,100],[0,100],'CNT',[ABSOLUTE,0],True]
mode2 = ['LPF2-CAL',[3,DATA16,3,0],[0,1023],[0,100],[0,1023],'RAW',[ABSOLUTE,0],False]
defaultModes = [mode0,mode1,mode2]     

def mode(name,size = 1, type=DATA8, format = '3.0',  raw = [0,100], percent = [0,100],  SI = [0,100], symbol = '', functionmap = [ABSOLUTE,0], view = True):
          fig,dec = format.split('.')
          fred = [name, [size,type,int(fig),int(dec)],raw,percent,SI,symbol,functionmap,view]
          return fred
               
class LPF2(object):
     def __init__(self, uartChannel, txPin, rxPin, modes = defaultModes, type = WeDo_Ultrasonic, timer = 4, freq = 5):
          self.txPin = txPin
          self.rxPin = rxPin
          self.uart = machine.UART(uartChannel)
          self.txTimer = timer
          self.modes = modes
          self.current_mode = 0
          self.type = type
          self.connected = False
          self.payload = bytearray([])
          self.freq = freq
          self.oldbuffer =  bytes([])
          self.textBuffer = bytearray(b'                ')
          
# -------- Payload definition

     def load_payload(self, type, array):   # note it must be a power of 2 length          
          if isinstance(array,list):
               bit = math.floor(math.log2(length[type]*len(array)))  
               bit = 4 if bit > 4 else bit     # max 16 bytes total (4 floats)
               array = array[:math.floor((2**bit)/ length[type])]     # max array size is 16 bytes
               value = b''
               for element in array:
                    value += struct.pack(format[type], element)
          else:
               bit = int(math.log2(length[type]))
               value = struct.pack(format[type], array)
          payload = bytearray([CMD_Data | (bit << CMD_LLL_SHIFT) | self.current_mode])+value
          self.payload = self.addChksm(payload)
          
#----- comm stuff

     def hubCallback(self, timerInfo):
     #def hubCallback(self):
          if self.connected:
               chr = self.uart.read(1)     # read in any heartbeat bytes
               if chr == None:
                   return
               chr = int.from_bytes(chr, "big")
               while chr >=0:
                    if chr != 2:
                         print ("SMYCKA") 
                         print (chr)
                    if chr == 0:   # port has nto been setup yet
                         pass
                    elif chr == BYTE_NACK:     # regular heartbeat pulse
                         self.watchdogTimer.deinit()
                         self.watchdogTimer = machine.Timer(-1, mode=machine.Timer.ONE_SHOT, period=1500, callback=self.wdgCallback )  # watchdog for 1500 ms
                         pass   
                    elif chr == CMD_Select:    # reset the mode
                         mode = int.from_bytes(self.uart.read(1), "big")
                         cksm = int.from_bytes(self.uart.read(1), "big")
                         print ("CMD_Select")
                         print (mode)
                         if cksm == 0xff ^ CMD_Select ^ mode:
                              self.current_mode = mode
                              print ("zmena modu")
                              print (mode)
                    elif chr == 0x46:     # sending over a string
                         zero = int.from_bytes(self.uart.read(1), "big")
                         b9 = int.from_bytes(self.uart.read(1), "big")
                         print ("0x46")
                         print (zero)
                         print (b9)
                         ck = 0xff ^ zero ^ b9
                         if ((zero == 0) & (b9 == 0xb9)):   # intro bytes for the string
                              char = int.from_bytes(self.uart.read(1), "big")    # size and mode
                              size = 2**((char & 0b111000)>>3)
                              mode = char & 0b111
                              print ("Velikost")
                              print (size)
                              print ("mod")
                              print (mode)
                              ck = ck ^ char
                              for i in range(len(self.textBuffer)):
                                   self.textBuffer[i] = ord(b' ')
                              for i in range(size):
                                   self.textBuffer[i] = int.from_bytes(self.uart.read(1), "big")
                                   ck = ck ^ self.textBuffer[i]
                              print (self.textBuffer)
                              print("".join("\\x%02x" % i for i in self.textBuffer))
                              cksm = int.from_bytes(self.uart.read(1), "big")
                              print(cksm)
                              print(ck)
                              if cksm == ck:
                                   print ("proslo")
                                   pass
                    elif chr == 0x4C:     # no idea what it is - but it sends a 0x20
                         thing = int.from_bytes(self.uart.read(1), "big")
                         cksm = int.from_bytes(self.uart.read(1), "big")
                         print ("0x4C")
                         print (thing)
                         if cksm == 0xff ^ 0x4C ^ thing:
                              print ("PROSLO")
                              pass
                    else:
                        a = 5
                        print ("Else")
                        print (chr)
                    chr = self.uart.read(1)
                    if chr == None:
                       break
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

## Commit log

2023-06-16 add CAD case files
    [CaseBottom.FCStd, CaseBottom.step, CaseBottom.stl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]
2023-06-16 add hardware and manufacturing files
    [BOMTemplateAssembly.xls, LEGO_VL53L1X_Sensor.PcbDoc, LEGO_VL53L1X_Sensor.PrjPcb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]
2023-06-20 added LED descriptions
2023-06-20 resize images, add Sensor_modification
2023-06-20 actualized Altium files and manufacturing data
    [LEGO_VL53L1X_Sensor.PcbDoc, LEGO_VL53L1X_Sensor.PrjPcb, STEP_LEGO_VL53L1X_Sensor_v0.2_2023-06-20_default_PetrVitek.step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]
